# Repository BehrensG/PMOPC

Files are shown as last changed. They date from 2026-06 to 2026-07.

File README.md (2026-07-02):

# PMOPC
Poor man's Optical Power Converter

# Introduction
Lately, I have come across the concept of Optical Power Converters (OPC), also known as Photonic Power Converters (PPC), which supply power to circuits using light and fiber optics. This technology is interesting to me for three main reasons: voltage isolation, immunity to common-mode noise and low noise output. For more information about OPC/PPC check : [What is an Optical to Electrical Converter?](https://www.photonics.com/Articles/The-Power-of-Light-Photonic-Power-Innovations-in/a25278). Commercial OPCs can deliver up to 3 W of power. However, the main drawback is that these devices are expensive — with receiver prices starting at approximately 500 euros and transmitters costing around 1,000 euros — and they are not easy to obtain. You can only get [Broadcom](https://www.broadcom.com/products/fiber-optic-modules-components/industrial/optical-power-components) products on  Mouser or DigiKey. A cheap alternative is to use a laser diode, plastic optical fiber, and a photodiode, as described in this paper on isolated sensor networks : [Isolated sensor networks for high-voltage environments using a single polymer optical fiber and LEDs for remote powering as well as data transmission](https://jsss.copernicus.org/articles/7/193/2018/). The downside to this photodiode approach is the limited output power, which is measured only in milliwatts. To overcome these limitations, the solution I would like to test is using infrared LEDs to shine on photovoltaic cells to generate output power.

# Design
Design was done using KiCAD 10.

## LED
Two layer PCB with 8x [SFH 4715AS](https://ams-osram.com/products/leds/ir-leds/osram-oslon-black-sfh-4715as) LEDs controlled with a current source.

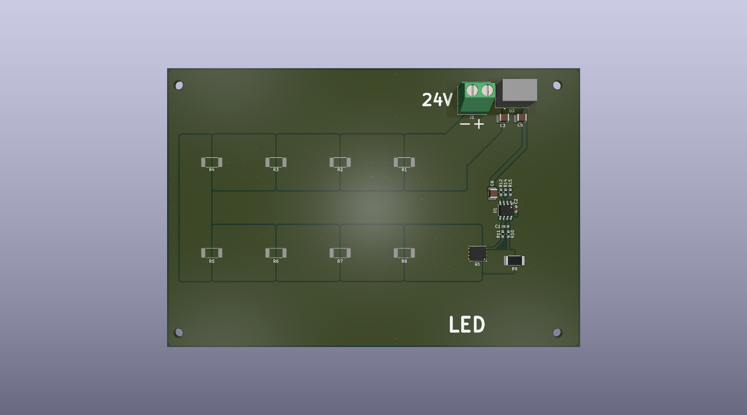
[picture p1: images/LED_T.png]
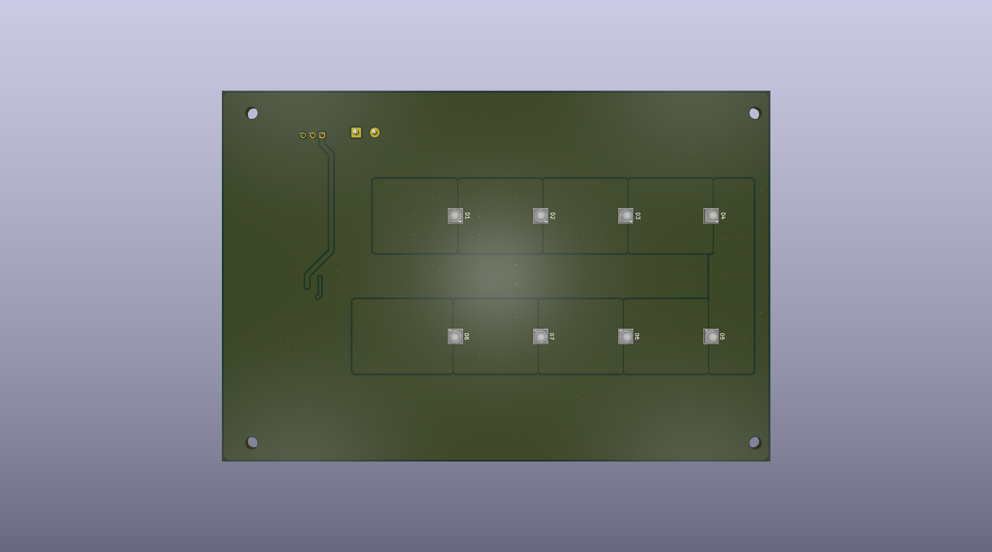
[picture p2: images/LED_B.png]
 

## OPC
Two layer PCB with 2x6 solar cell matrix using [SM111K09L](https://waf-e.dubudisk.com/anysolar.dubuplus.com/techsupport@anysolar.biz/O18Adzr/DubuDisk/www/Gen2/SM111K09L%20DATA%20SHEET%20202007.pdf).

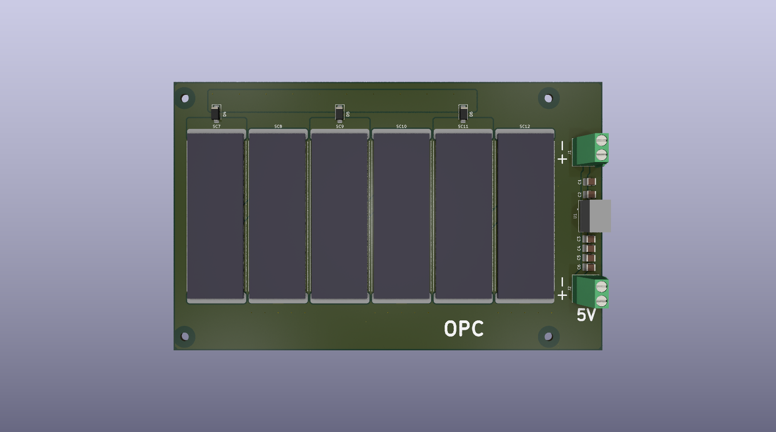
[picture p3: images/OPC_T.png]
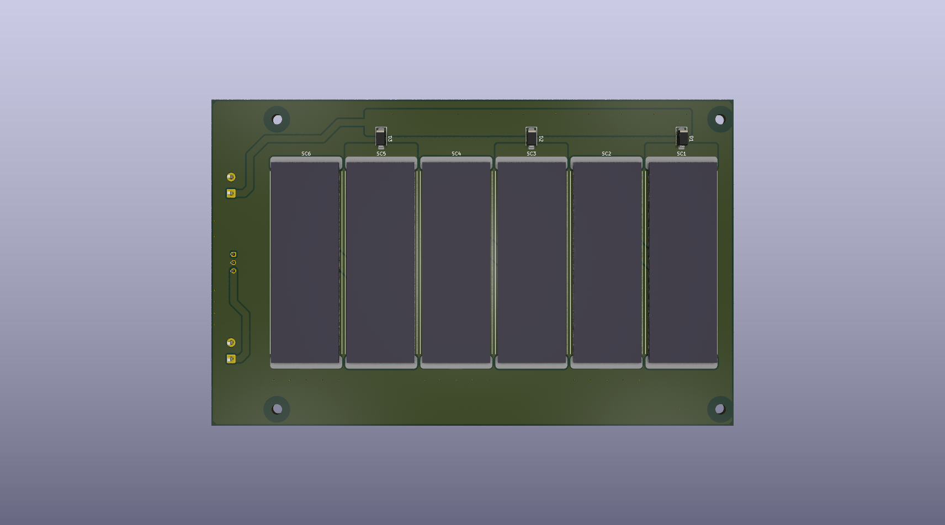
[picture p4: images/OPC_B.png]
 

# Implementation

I mounted only four solar cells due to the layout of the LED board design. Since each solar cell requires two LEDs and the LED board accommodates a maximum of eight LEDs, four cells is the limit. The 8 LED limits is because I want to use 24V max. 

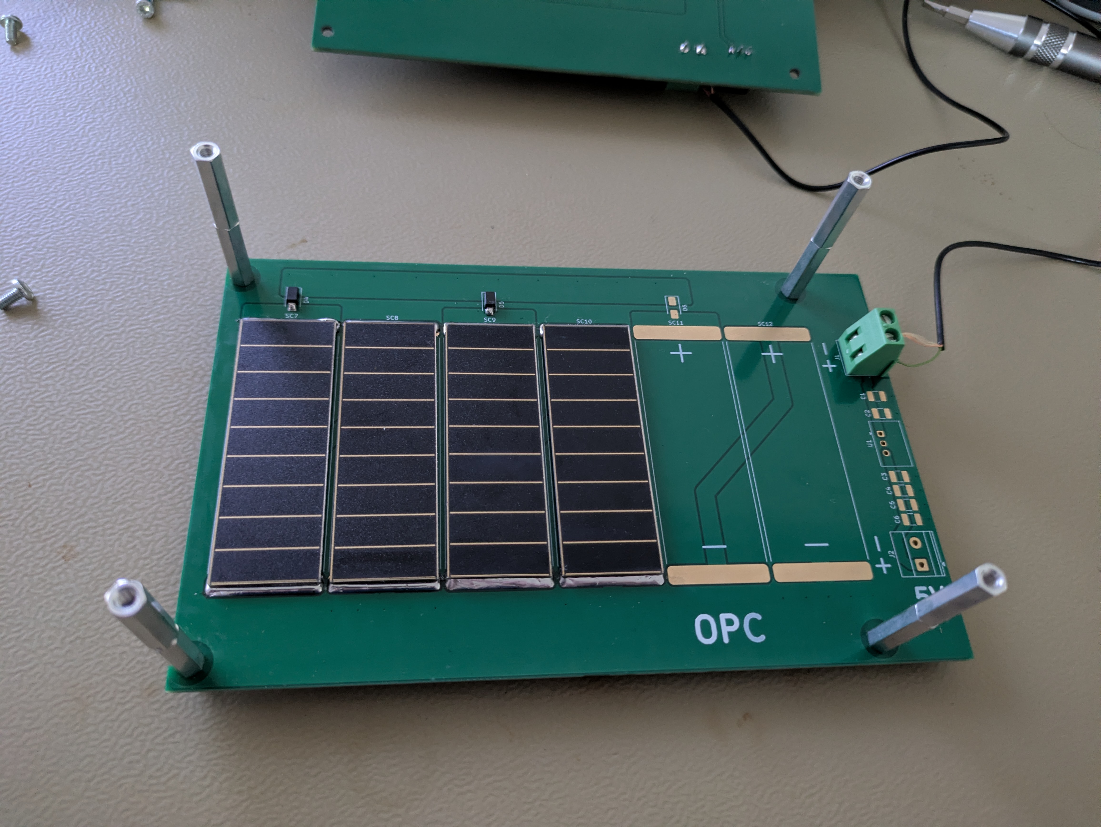
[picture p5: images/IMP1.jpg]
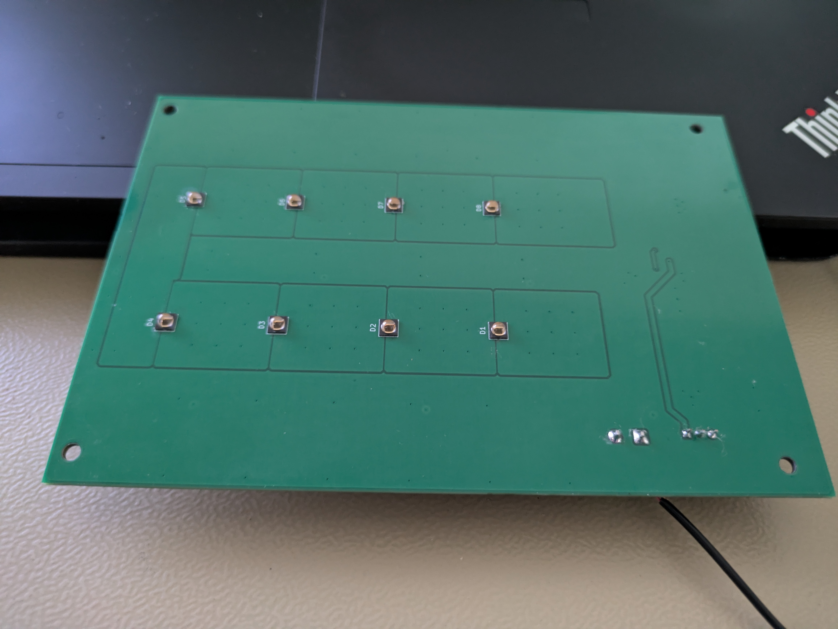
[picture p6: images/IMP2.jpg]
 

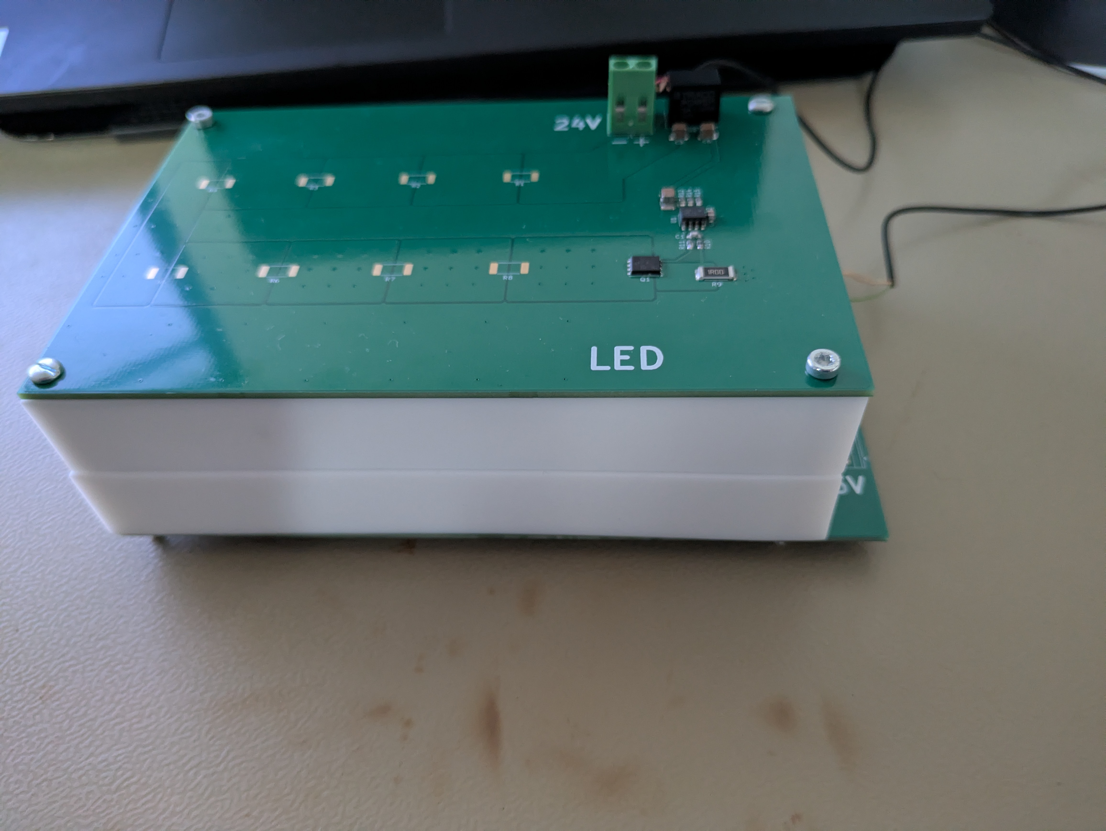
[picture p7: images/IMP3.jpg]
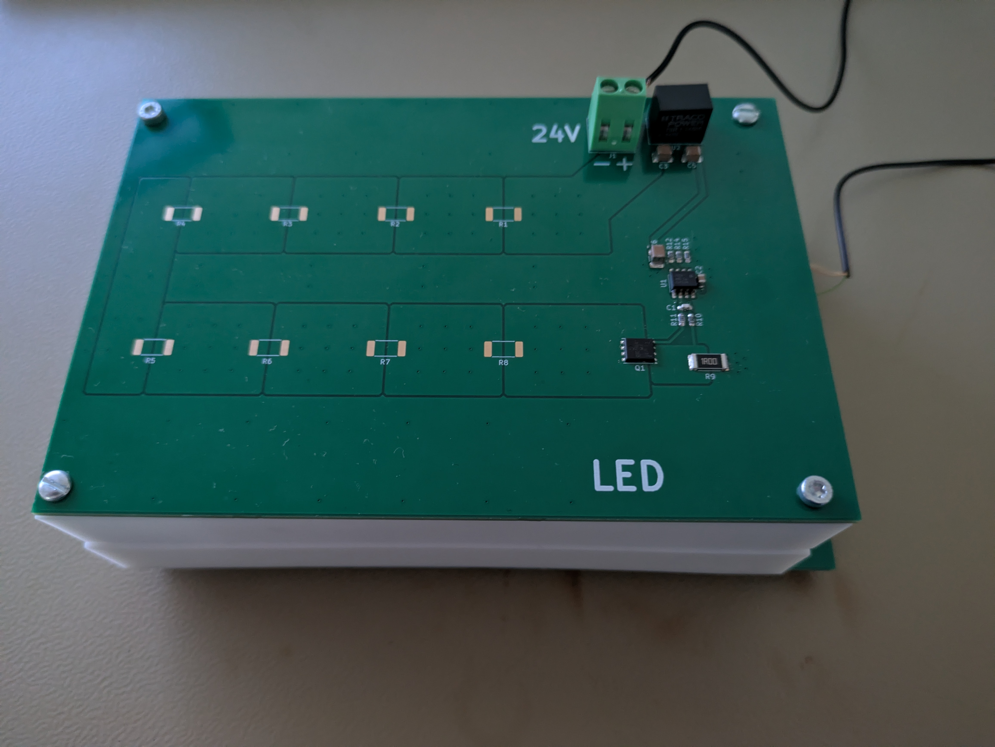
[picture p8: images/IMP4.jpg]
 

# Measurements

Used a 34410A DMM for voltage and current measurements. Measurement done for two distance between OPC-LED : 20 mm and 40 mm.

<figure align="center">
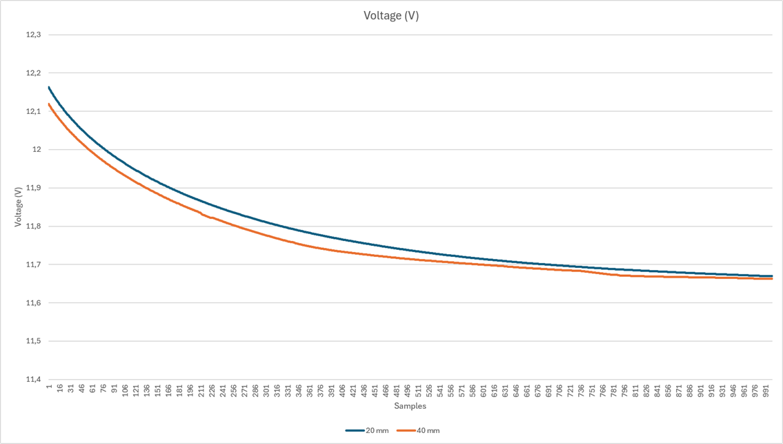
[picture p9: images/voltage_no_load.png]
  
  <figcaption>Figure 1: Open circuit voltage measurement. The LEDs were cooled with a fan. DMM: PLC 10, 1000 samples.</figcaption>
</figure>
<br><br>

<figure align="center">
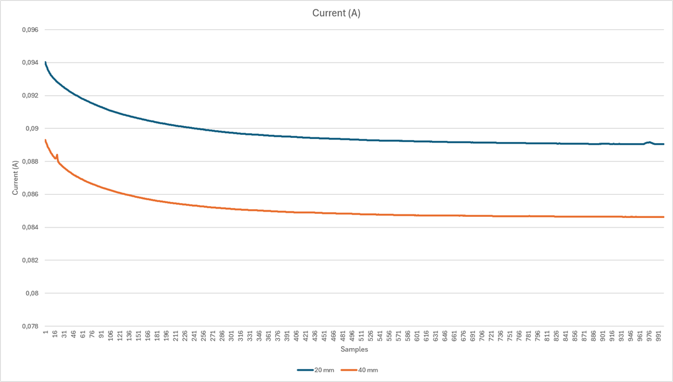
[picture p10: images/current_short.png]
  
  <figcaption>Figure 2: Short circuit current measurement. The LEDs were cooled with a fan. DMM: PLC 10, 1000 samples.</figcaption>
</figure>
<br><br>

<figure align="center">
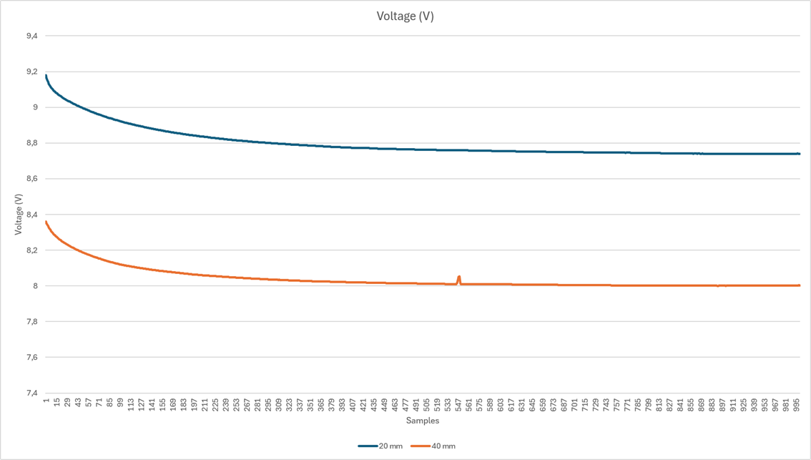
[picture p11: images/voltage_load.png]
  
  <figcaption>Figure 3: Voltage measurement with 110 ohm load. The LEDs were cooled with a fan. DMM: PLC 10, 1000 samples.</figcaption>
</figure>
<br><br>

<figure align="center">
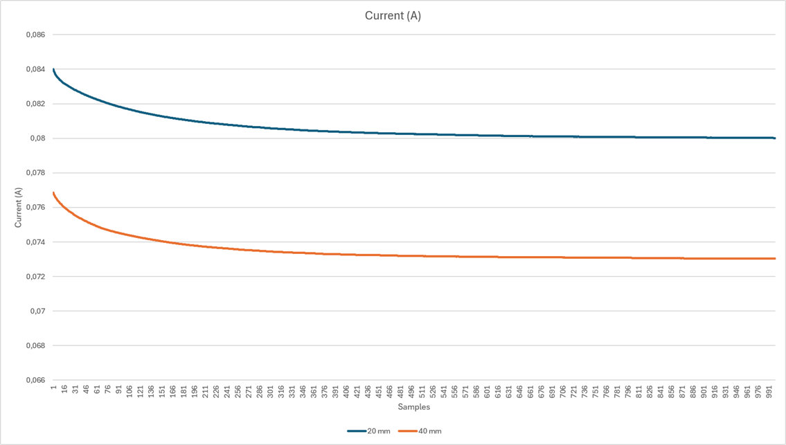
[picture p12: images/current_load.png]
  
  <figcaption>Figure 4: Current measurement with 110 ohm load. The LEDs were cooled with a fan. DMM: PLC 10, 1000 samples.</figcaption>
</figure>
<br><br>

<figure align="center">
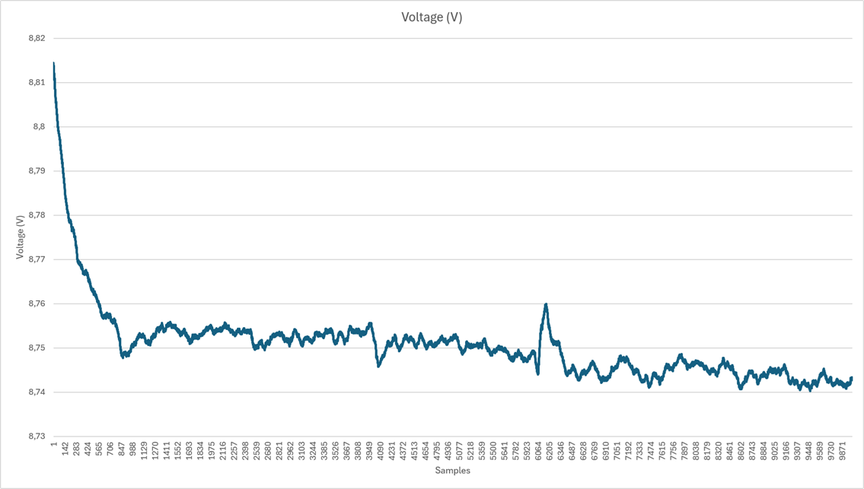
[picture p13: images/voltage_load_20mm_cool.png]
  
  <figcaption>Figure 5: Voltage measurement with 110 ohm load. The LEDs and solar cells were cooled with a fan. DMM: PLC 10, 10000 samples. Distance 20 mm.</figcaption>
</figure>
<br><br>

<figure align="center">
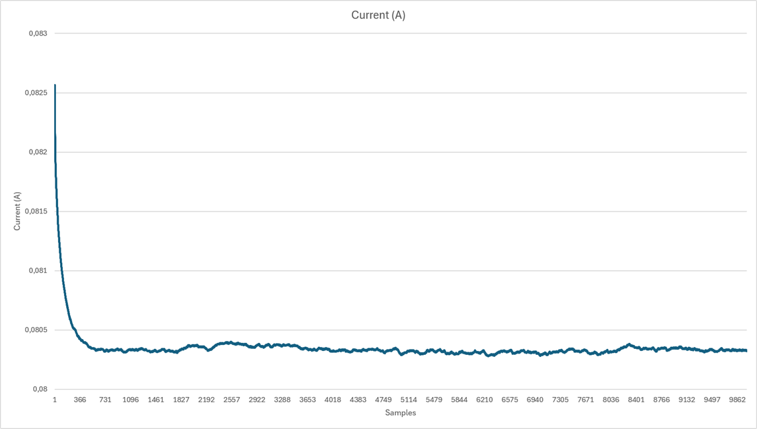
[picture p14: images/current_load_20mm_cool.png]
  
  <figcaption>Figure 6: Current measurement with 110 ohm load. The LEDs and solar cells were cooled with a fan. DMM: PLC 10, 10000 samples. Distance 20 mm.</figcaption>
</figure>

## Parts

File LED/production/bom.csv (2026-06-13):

Designator | Footprint | Quantity | Value | LCSC Part #
C1 | 0603 | 1 | 100p/100V/X7R
C2 | 0603 | 1 | 0.1u/100V/X7R
C3, C5, C6 | 1210 | 3 | 22u/25V/X7R
D1, D2, D3, D4, D5, D6, D7, D8 | SFH4715AS | 8 | SFH 4715AS
J1 | TerminalBlock_Phoenix_MKDS-1,5-2_1x02_P5.00mm_Horizontal | 1 | 1715721
Q1 | TDSON-8-1 | 1 | CSD18501Q5A
R1, R2, R3, R4, R5, R6, R7, R8 | 2512 | 8 | 0R/5%/250mW
R10 | 0603 | 1 | 1k/1%/100mW
R11 | 0603 | 1 | 100/1%/100mW
R12 | 0603 | 1 | 100k/0.1%/100mW
R14 | 0603 | 1 | 11k/0.1%/100mW
R15 | 0603 | 1 | 110/0.1%/100mW
R9 | 2512 | 1 | RNCL2512FT1R00
U1 | SOIC-8_3.9x4.9mm_P1.27mm | 1 | OPA192IDR
U2 | Converter_DCDC_TRACO_TSR1-xxxxE_THT | 1 | TSR1-2450E

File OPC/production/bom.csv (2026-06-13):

Designator | Footprint | Quantity | Value | LCSC Part #
C1, C2, C3, C4, C5, C6 | 1210 | 6 | 22u/25V/X7R
D1, D2, D3, D4, D5, D6 | D_SMA | 6 | SS14
J1, J2 | TerminalBlock_Phoenix_MKDS-1,5-2_1x02_P5.00mm_Horizontal | 2 | 1715721
SC1, SC10, SC11, SC12, SC2, SC3, SC4, SC5, SC6, SC7, SC8, SC9 | SM111K09L | 12 | SM111K09L
U1 | Converter_DCDC_TRACO_TSR1-xxxxE_THT | 1 | TSR1-2450E

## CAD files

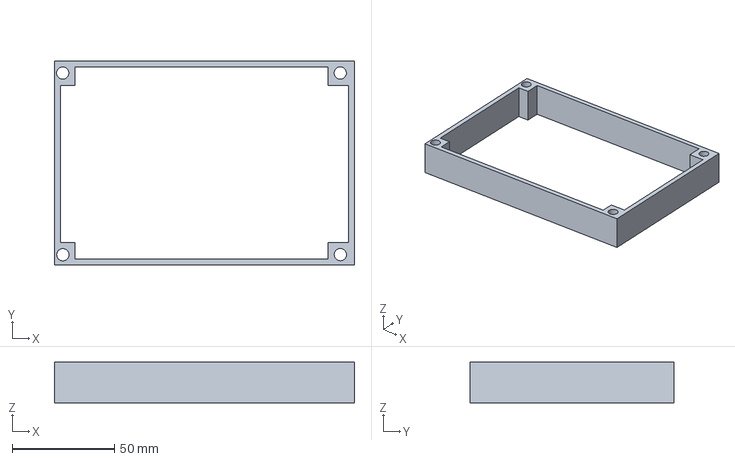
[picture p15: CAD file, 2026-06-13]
CAD/Distance.FCStd
147.0 x 100.0 x 20.0 mm

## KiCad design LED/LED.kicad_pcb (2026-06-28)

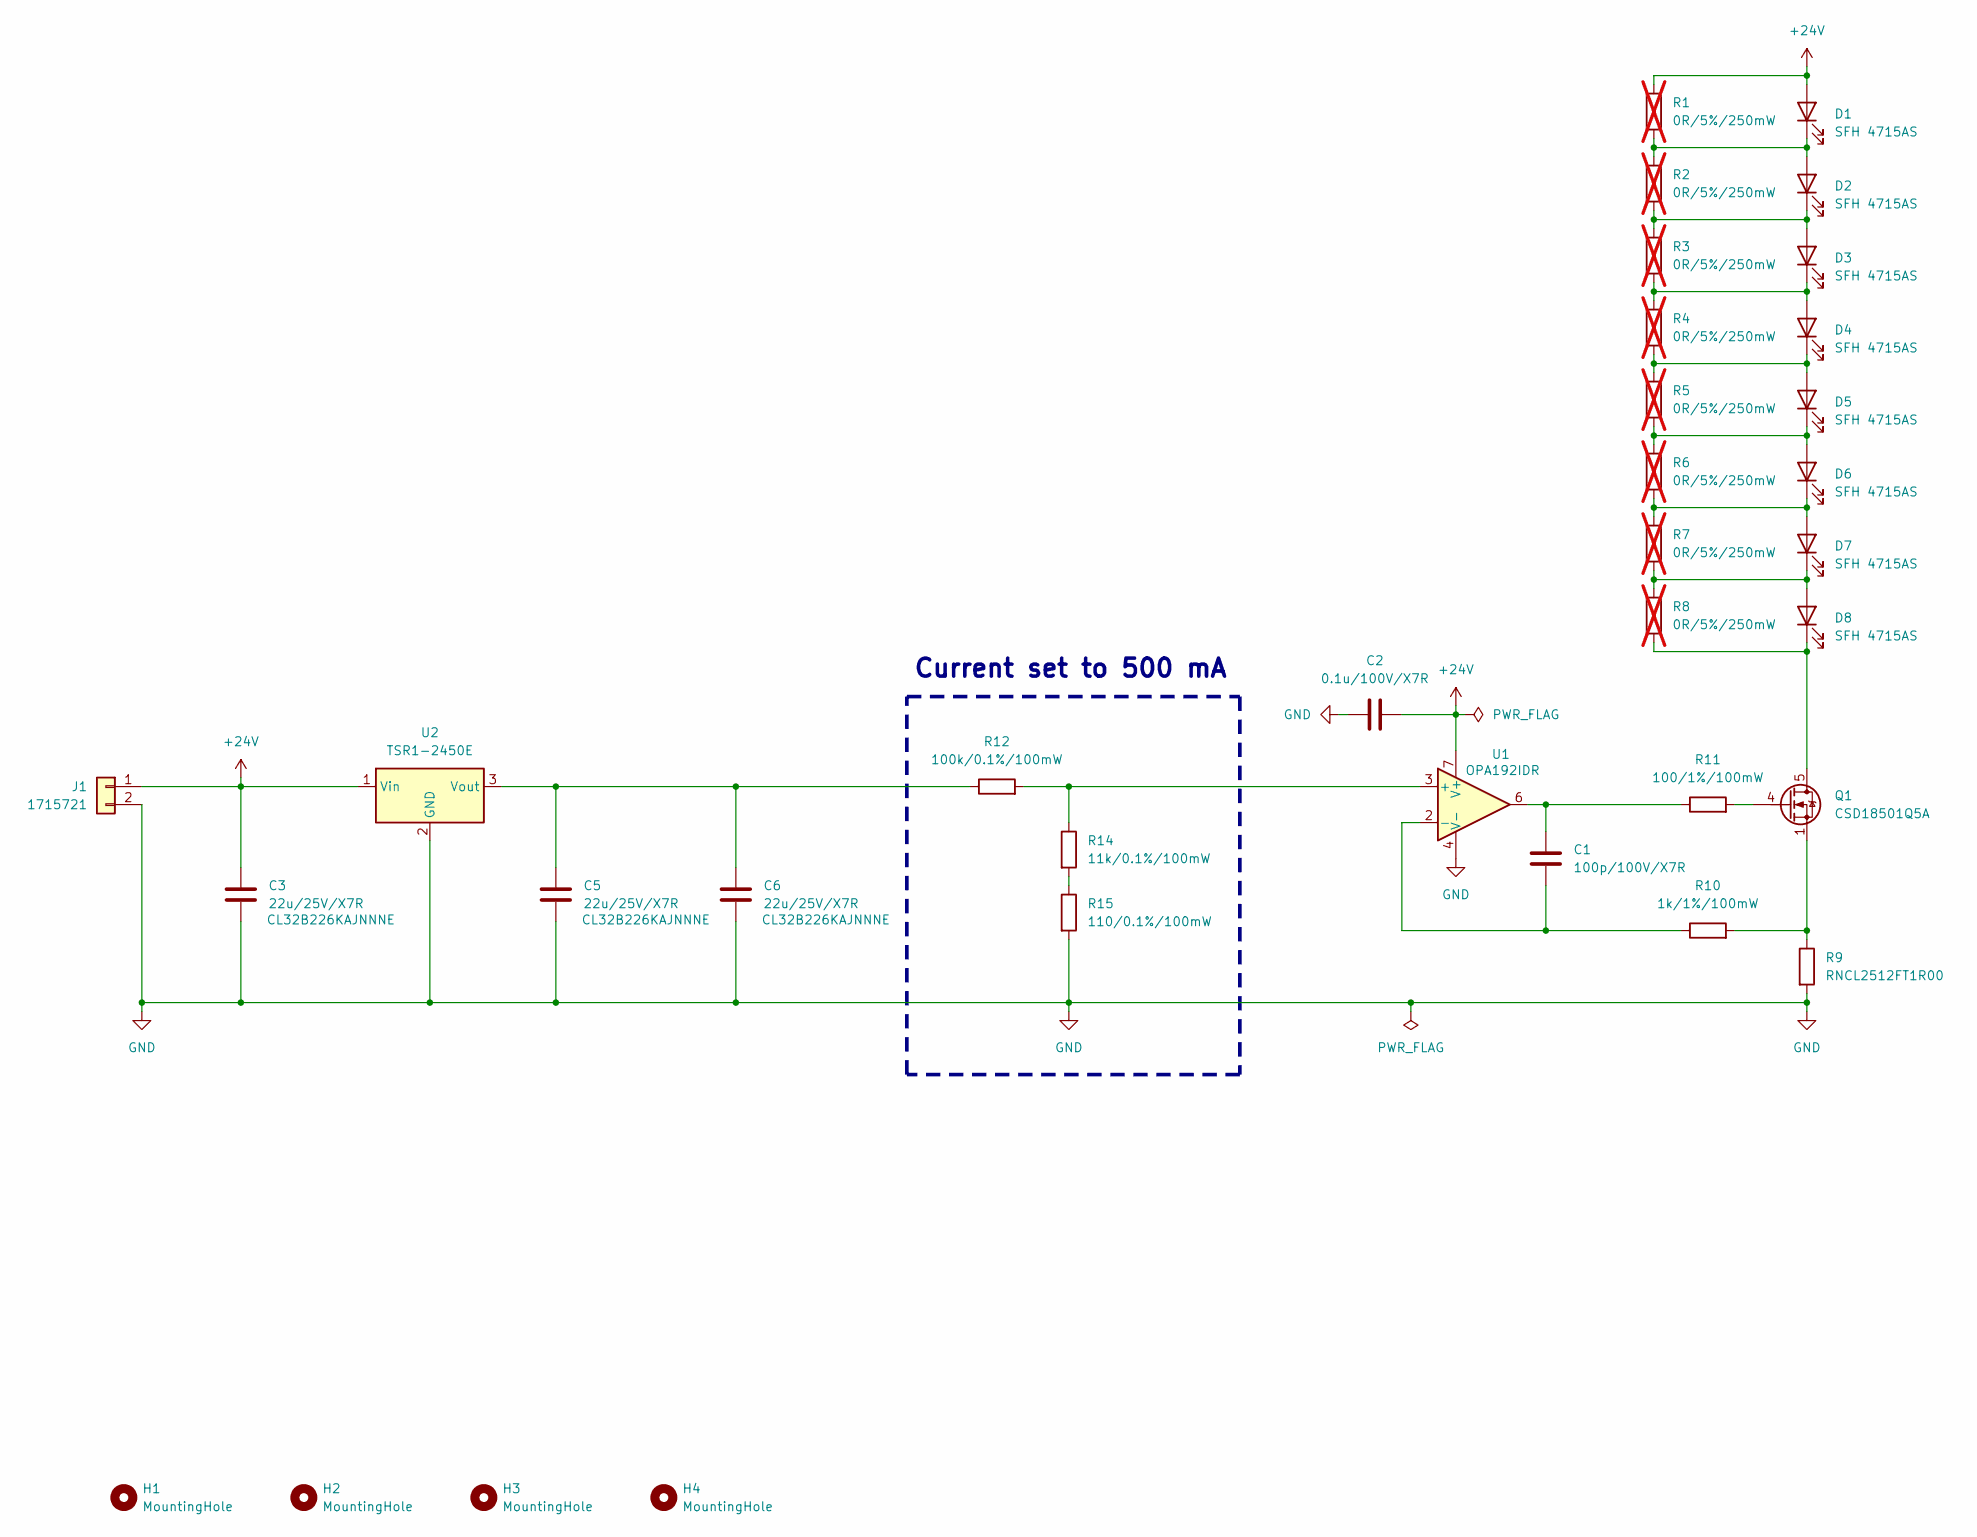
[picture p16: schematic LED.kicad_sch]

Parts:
C1: 100p/100V/X7R; C_0603_1608Metric_Pad1.08x0.95mm_HandSolder
C2: 0.1u/100V/X7R; C_0603_1608Metric_Pad1.08x0.95mm_HandSolder
C3, C5, C6: 22u/25V/X7R; C_1210_3225Metric_Pad1.33x2.70mm_HandSolder
D1, D2, D3, D4, D5, D6, D7, D8: SFH 4715AS; SFH4715AS
H1, H2, H3, H4: MountingHole; MountingHole_3.2mm_M3_DIN965
J1: 1715721; TerminalBlock_Phoenix_MKDS-1,5-2_1x02_P5.00mm_Horizontal
Q1: CSD18501Q5A; TDSON-8-1
R1, R2, R3, R4, R5, R6, R7, R8: 0R/5%/250mW; R_2512_6332Metric_Pad1.40x3.35mm_HandSolder; not fitted
R9: RNCL2512FT1R00; R_2512_6332Metric_Pad1.40x3.35mm_HandSolder
R10: 1k/1%/100mW; R_0603_1608Metric_Pad0.98x0.95mm_HandSolder
R11: 100/1%/100mW; R_0603_1608Metric_Pad0.98x0.95mm_HandSolder
R12: 100k/0.1%/100mW; R_0603_1608Metric_Pad0.98x0.95mm_HandSolder
R14: 11k/0.1%/100mW; R_0603_1608Metric_Pad0.98x0.95mm_HandSolder
R15: 110/0.1%/100mW; R_0603_1608Metric_Pad0.98x0.95mm_HandSolder
U1: OPA192IDR; SOIC-8_3.9x4.9mm_P1.27mm
U2: TSR1-2450E; Converter_DCDC_TRACO_TSR1-xxxxE_THT

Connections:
+24V: C2.2, C3.1, D1.2 (A), J1.1, R1.1, U1.7 (V+), U2.1 (Vin)
GND: C2.1, C3.2, C5.2, C6.2, J1.2, R9.2, R15.2, U1.4 (V-), U2.2 (GND)
unnamed: C1.1, R11.1, U1.6
unnamed: D1.1 (K), D2.2 (A), R1.2, R2.1
unnamed: D2.1 (K), D3.2 (A), R2.2, R3.1
unnamed: D3.1 (K), D4.2 (A), R3.2, R4.1
unnamed: D4.1 (K), D5.2 (A), R4.2, R5.1
unnamed: D5.1 (K), D6.2 (A), R5.2, R6.1
unnamed: D6.1 (K), D7.2 (A), R6.2, R7.1
unnamed: D7.1 (K), D8.2 (A), R7.2, R8.1
unnamed: D8.1 (K), Q1.5 (D), R8.2
unnamed: Q1.4 (G), R11.2
unnamed: Q1.1 (S), Q1.2 (S), Q1.3 (S), R9.1, R10.2
unnamed: R14.2, R15.1
unnamed: R12.2, R14.1, U1.3 (+)
unnamed: C1.2, R10.1, U1.2 (-)
unnamed: C5.1, C6.1, R12.1, U2.3 (Vout)

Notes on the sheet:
Current set to 500 mA

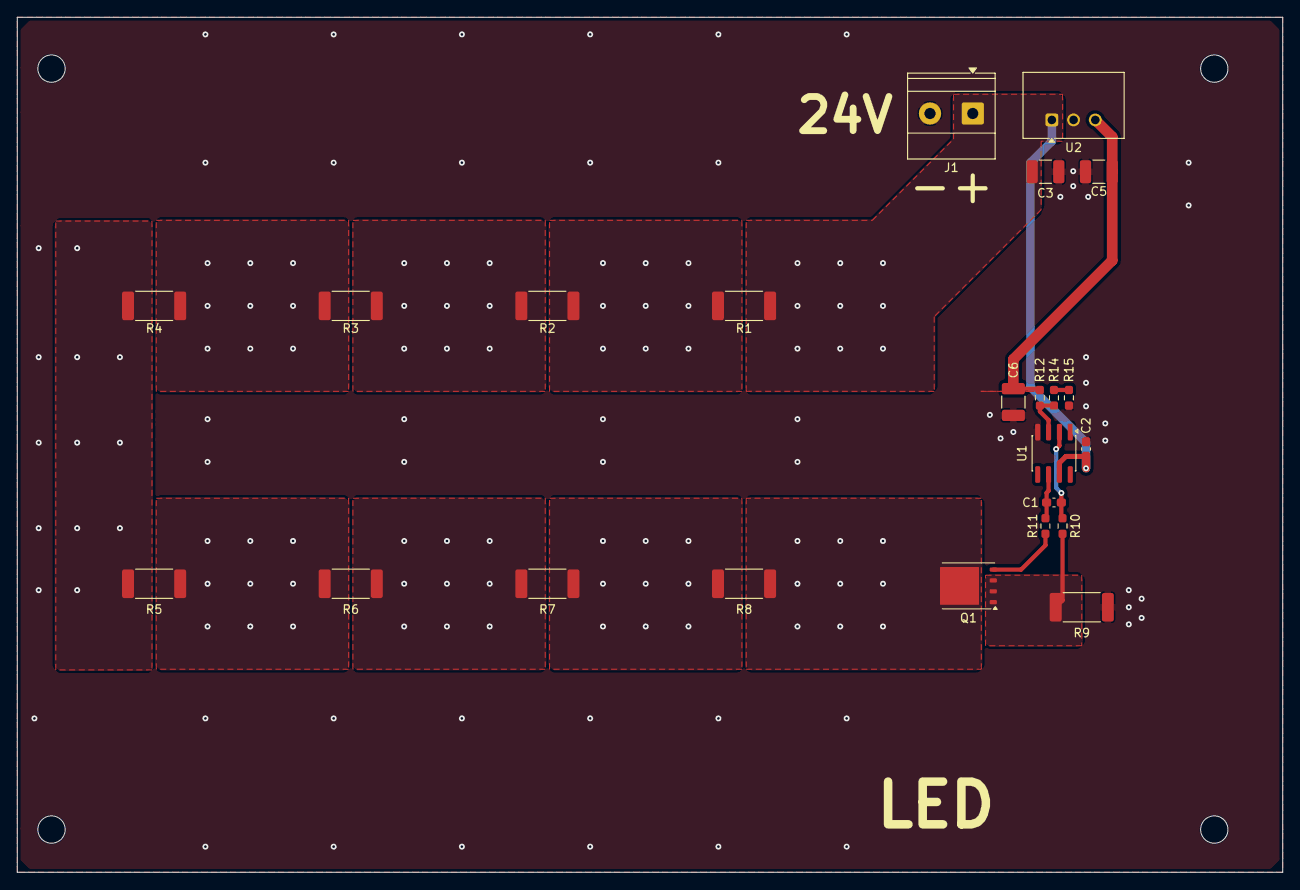
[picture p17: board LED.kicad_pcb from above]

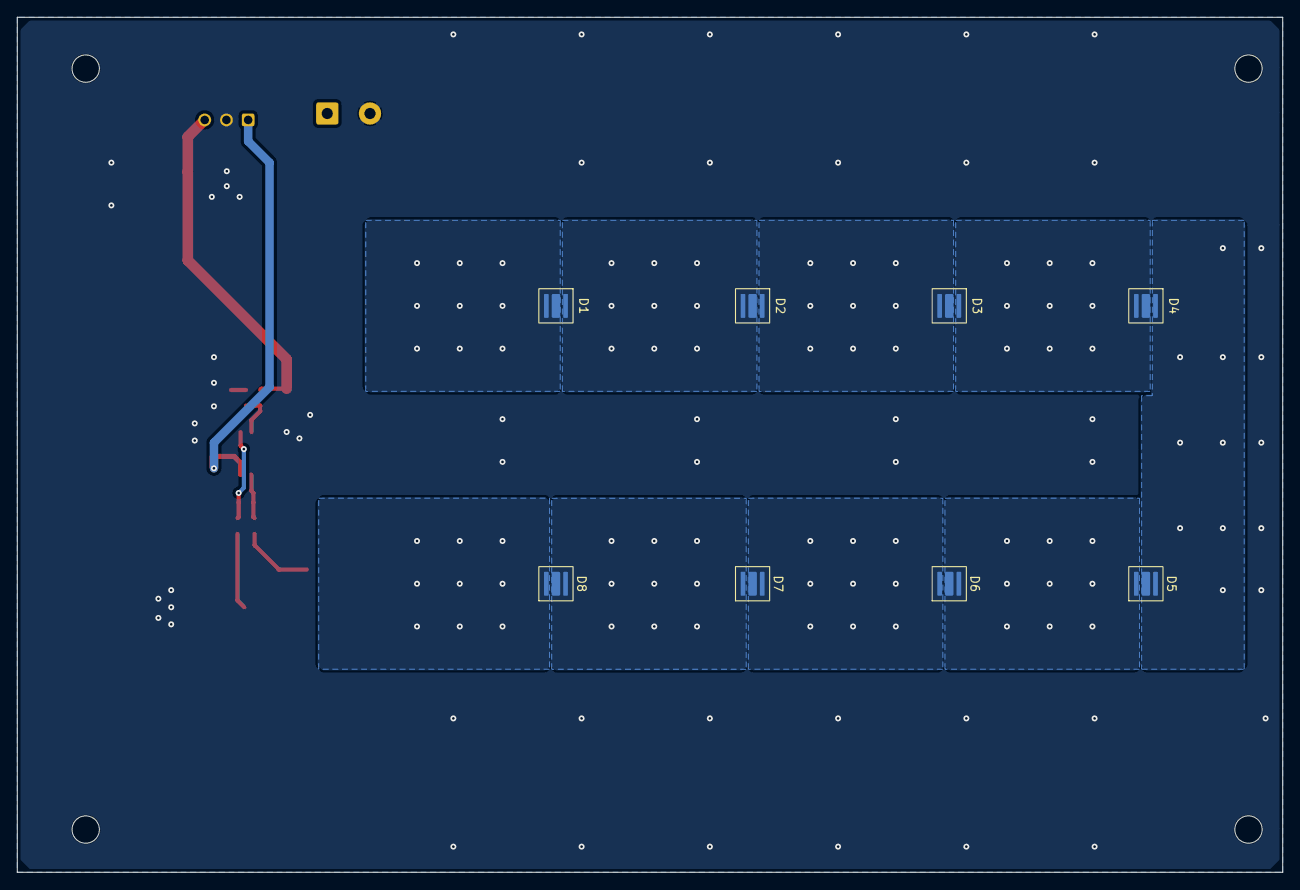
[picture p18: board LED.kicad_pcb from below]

Board: 2 copper layers, 148.0 x 100.0 mm, 35 parts (8 on the bottom side), 17 nets.

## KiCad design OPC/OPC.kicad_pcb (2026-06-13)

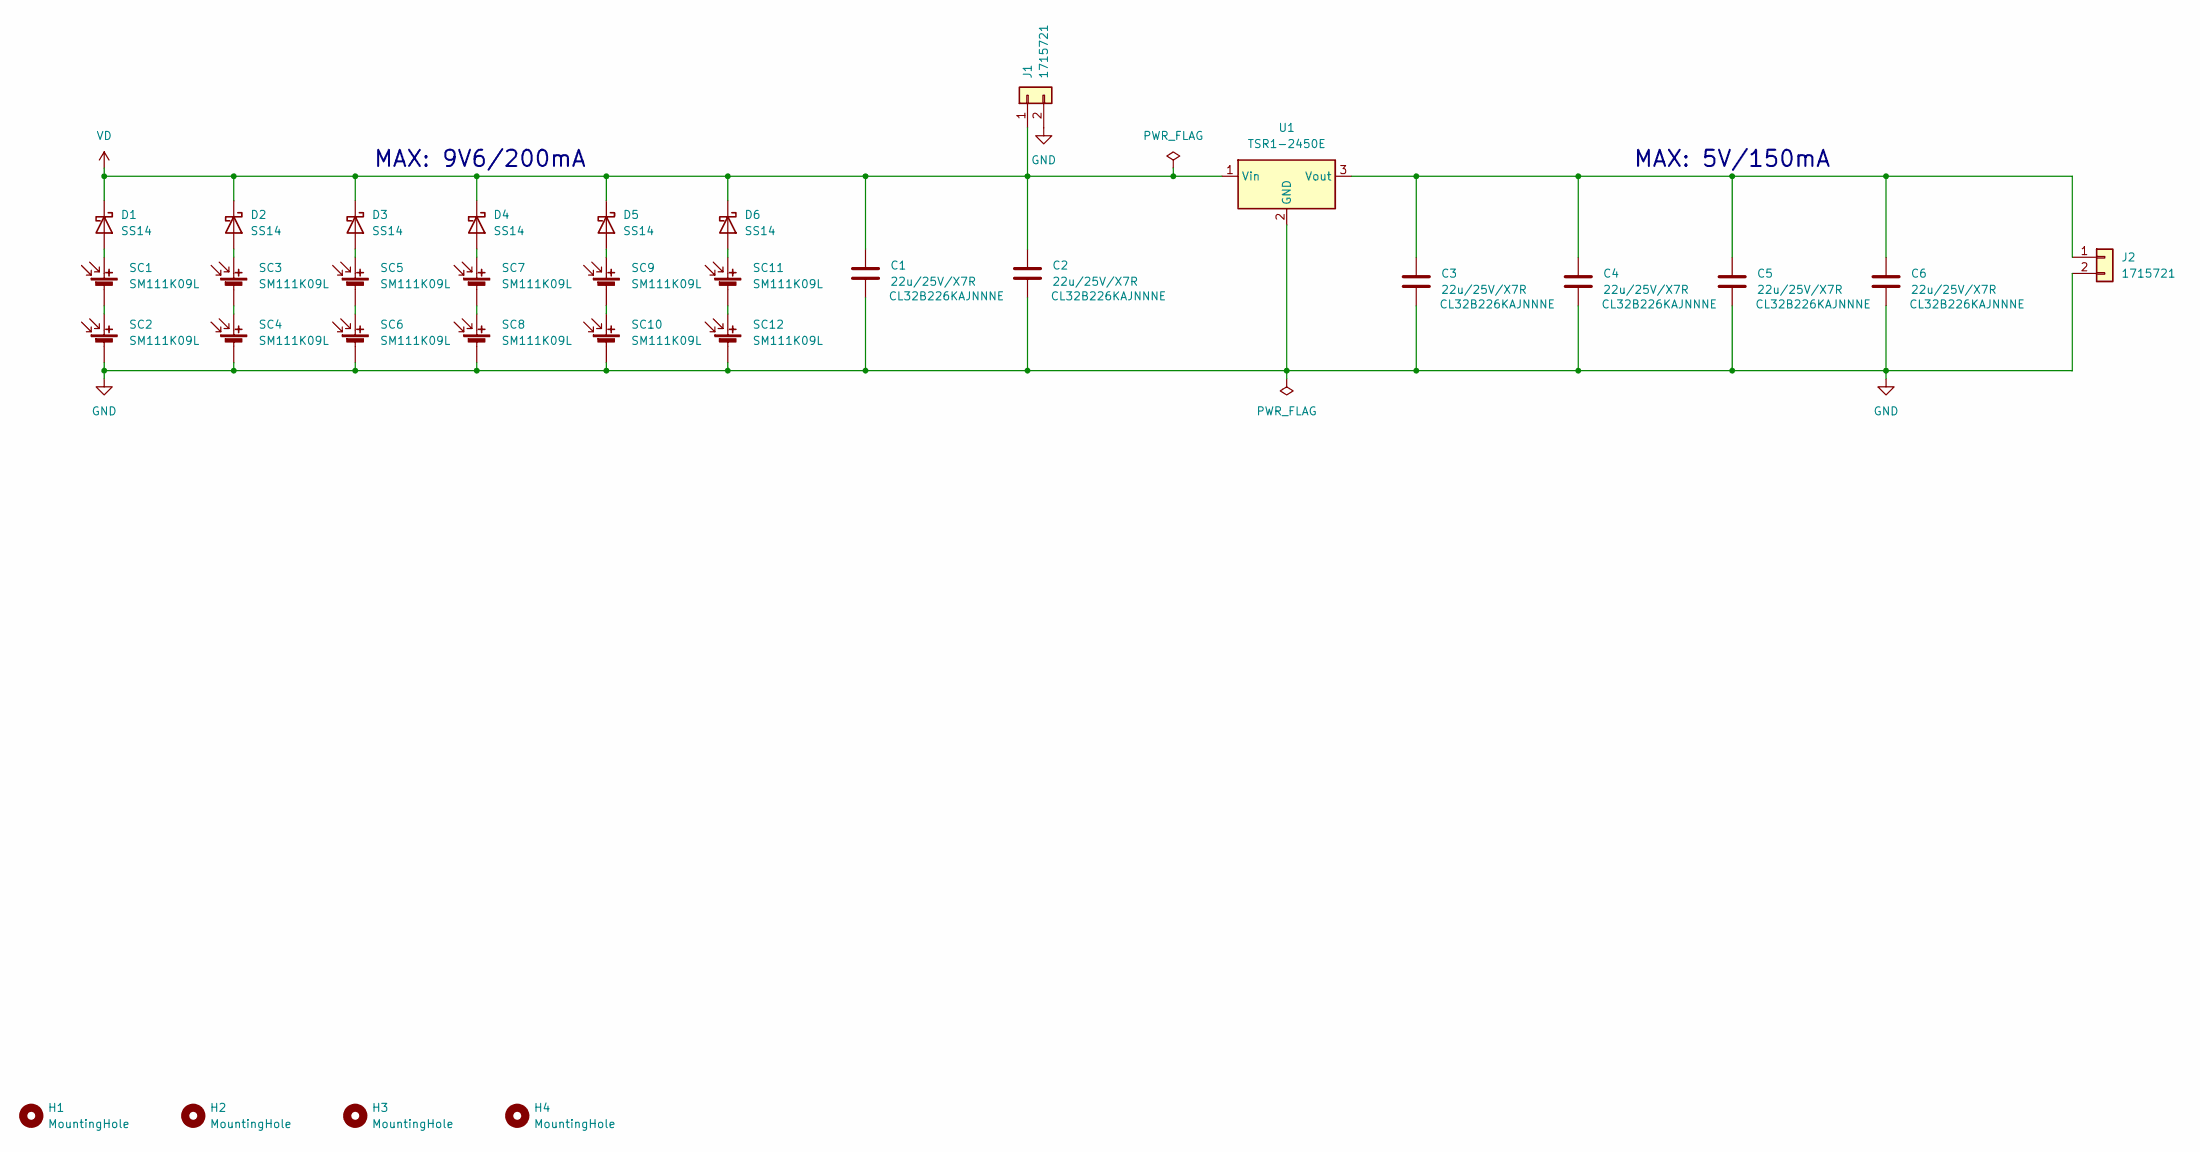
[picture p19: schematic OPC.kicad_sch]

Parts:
C1, C2, C3, C4, C5, C6: 22u/25V/X7R; C_1210_3225Metric_Pad1.33x2.70mm_HandSolder
D1, D2, D3, D4, D5, D6: SS14; D_SMA
H1, H2, H3, H4: MountingHole; MountingHole_3.2mm_M3_DIN965
J1, J2: 1715721; TerminalBlock_Phoenix_MKDS-1,5-2_1x02_P5.00mm_Horizontal
SC1, SC2, SC3, SC4, SC5, SC6, SC7, SC8, SC9, SC10, SC11, SC12: SM111K09L
U1: TSR1-2450E; Converter_DCDC_TRACO_TSR1-xxxxE_THT

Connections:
GND: C1.2, C2.2, C3.2, C4.2, C5.2, C6.2, J1.2, J2.2, SC2.2 (-), SC4.2 (-), SC6.2 (-), SC8.2 (-), SC10.2 (-), SC12.2 (-), U1.2 (GND)
unnamed: D1.2 (A), SC1.1 (+)
unnamed: D2.2 (A), SC3.1 (+)
unnamed: D3.2 (A), SC5.1 (+)
unnamed: D4.2 (A), SC7.1 (+)
unnamed: D5.2 (A), SC9.1 (+)
unnamed: D6.2 (A), SC11.1 (+)
unnamed: C3.1, C4.1, C5.1, C6.1, J2.1, U1.3 (Vout)
unnamed: SC1.2 (-), SC2.1 (+)
unnamed: SC3.2 (-), SC4.1 (+)
unnamed: SC5.2 (-), SC6.1 (+)
unnamed: SC7.2 (-), SC8.1 (+)
unnamed: SC9.2 (-), SC10.1 (+)
unnamed: SC11.2 (-), SC12.1 (+)
VD: C1.1, C2.1, D1.1 (K), D2.1 (K), D3.1 (K), D4.1 (K), D5.1 (K), D6.1 (K), J1.1, U1.1 (Vin)

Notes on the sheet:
MAX: 5V/150mA
MAX: 9V6/200mA

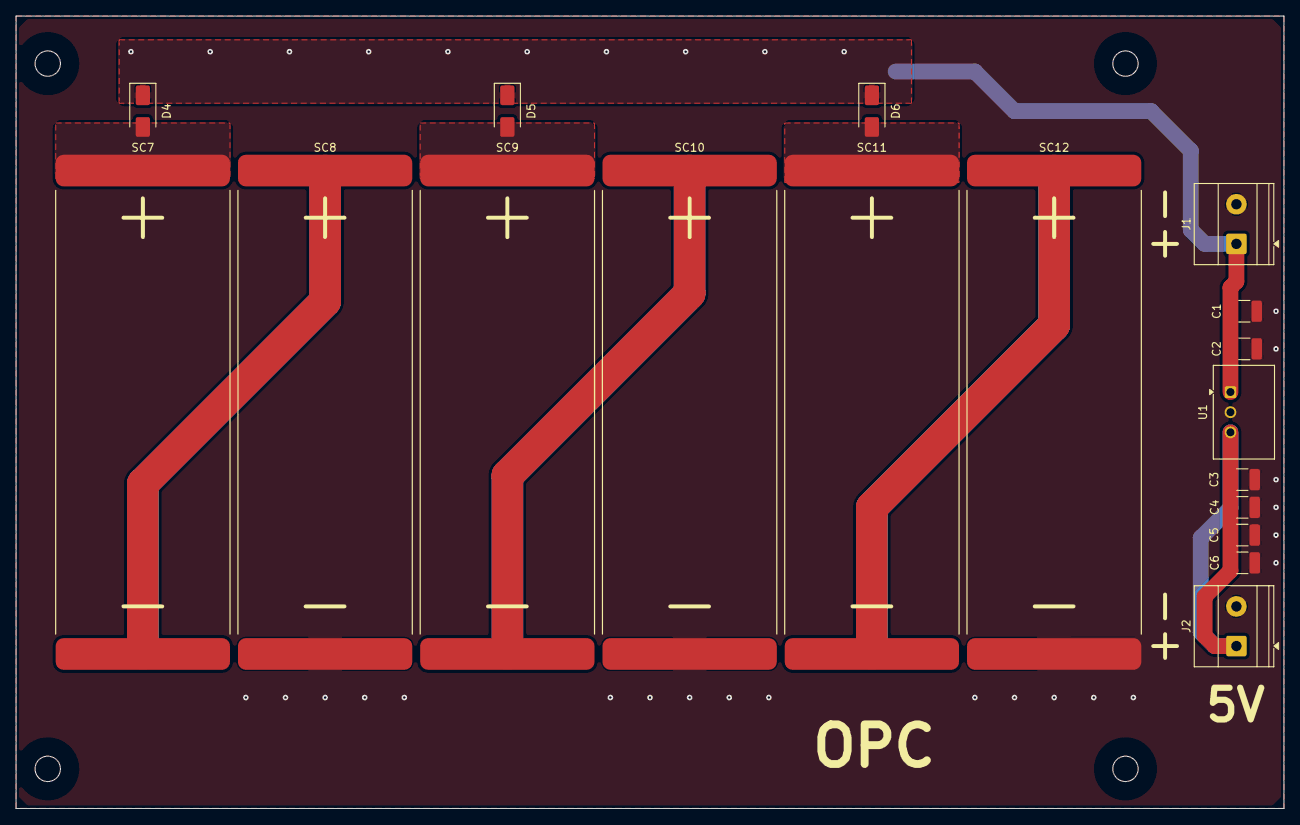
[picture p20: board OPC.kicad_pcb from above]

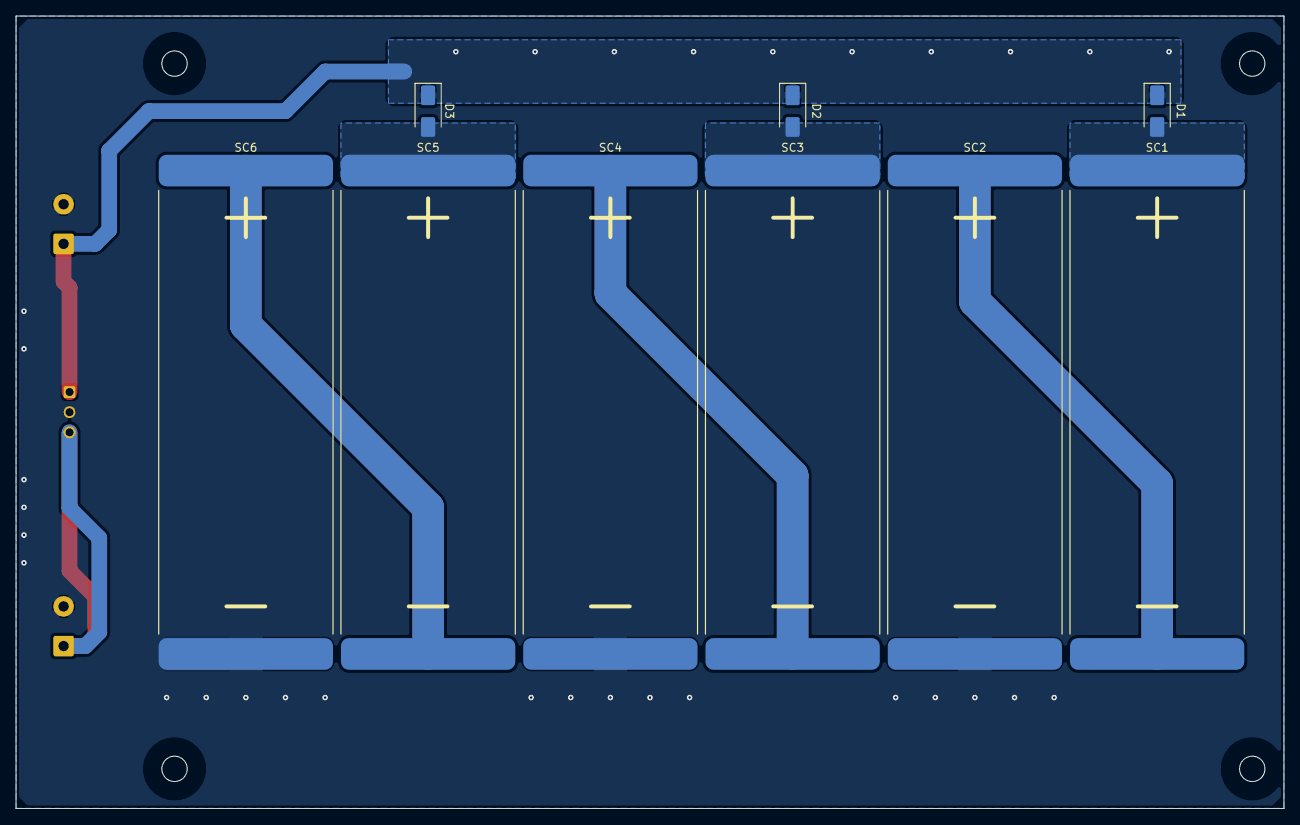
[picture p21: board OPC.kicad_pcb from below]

Board: 2 copper layers, 160.0 x 100.0 mm, 31 parts (9 on the bottom side), 15 nets.

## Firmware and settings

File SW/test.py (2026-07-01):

import pyvisa
import csv 
rm = pyvisa.ResourceManager()

dmm = rm.open_resource('TCPIP0::192.168.1.3::5025::SOCKET')
dmm.write_termination = '\n'
dmm.read_termination = '\n'
dmm.timeout = 1000 
print(dmm.query('*IDN?'))
dmm.write('*RST')
dmm.write('*CLS')
dmm.write('CONF:VOLT:DC AUTO')
dmm.write('SENS:VOLT:DC:NPLC 10')
filename = "volt_load_20mm_cool.csv"

with open(filename, mode='w', newline='') as file:
    writer = csv.writer(file)
    # Write only the column header
    writer.writerow(['Voltage (V)'])
    
    for i in range(1, 10001):
        
        voltage = float(dmm.query('READ?'))
        print(f'Sample : {i}, READ : {voltage}')
        writer.writerow([voltage])

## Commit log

2026-06-13 Design done
    [Distance.FCStd, LED.kicad_pcb, LED.kicad_sch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]
2026-06-28 Updated README file
    [LED.kicad_pcb, LED.kicad_sch]
2026-07-01 Measurement software
    [curr_load_20mm.csv, curr_load_20mm_cool.csv, curr_load_40mm.csv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]
2026-07-02 Measurements and README changes
    [curr_load_20mm.csv, curr_load_40mm.csv, curr_short_20mm.csv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]
